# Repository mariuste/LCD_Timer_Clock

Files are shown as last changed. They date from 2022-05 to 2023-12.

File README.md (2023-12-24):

# Light Alarm Clock and Timer"
# Project Parameters
Name: "Light Alarm Clock and Timer"
Description: "Open Source, Alarm Clock with battery backup and USB-C Power"
Short Name: "Alarm_Clock"

# Description
/TODO/

# ToDos
- create requirements for redesign (single eval board, optimize encoder)
- define critical components (speakter interface)
- create schematic
- create layout

# Requirements for LED_board Mk2

## Changes to previous version

# Part selection
| Part | Manufacturer | Part Number |
|---|---|---|
| MCU | STM | STM32L011F3U6TR | /TBD/ other type

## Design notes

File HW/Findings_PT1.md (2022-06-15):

Findings

PCB_TOP
- variant problem in BOM (R502) -> [Issue #1](https://github.com/mariuste/LCD_Timer_Clock/issues/1)
- BTN LED resistor missing (here or on PCB-BOT); yellow 2k and green 16k -> [Issue #2](https://github.com/mariuste/LCD_Timer_Clock/issues/2)
- Identifier in solder mask wrong (top - bot) -> [Issue #3](https://github.com/mariuste/LCD_Timer_Clock/issues/3)
- Export File name missing "TOP" -> [Issue #4](https://github.com/mariuste/LCD_Timer_Clock/issues/4)
- IC503, IC504, IC505 EP is LED pin, not GND -> [Issue #5](https://github.com/mariuste/LCD_Timer_Clock/issues/5)
- add vias to LEDs to transport heat (full connection) -> [Issue #7](https://github.com/mariuste/LCD_Timer_Clock/issues/7)
- add heat sink from bottom -> [Issue #7](https://github.com/mariuste/LCD_Timer_Clock/issues/7)
- LCD_Keypad_PWM not connected -> bridge with BG PWM -> [Issue #8](https://github.com/mariuste/LCD_Timer_Clock/issues/8)
- add cover to BTN LEDs (too bright), maybe drill holes for mounting something -> [Issue #9](https://github.com/mariuste/LCD_Timer_Clock/issues/9)
- rename Set LED to Time_Date LED and other signals ("T" missing) -> [Issue #10](https://github.com/mariuste/LCD_Timer_Clock/issues/10)
- schematic net name timer / quicksetting not consistent with LEDs -> [Issue #10](https://github.com/mariuste/LCD_Timer_Clock/issues/10)
- Timer 1 LED is connected to signal Timer 2 and vice versa (for now fixed in sw) -> [Issue #10](https://github.com/mariuste/LCD_Timer_Clock/issues/10)
- LCD VDD too low, above 3V3 working -> use VBAT, mind voltage levels -> [Issue #11](https://github.com/mariuste/LCD_Timer_Clock/issues/11)
- LED not yellow enugh, replace with warmer color, e.g. XTEAWT-00-0000-00000LAEATR-ND or 475-GWQSSPA1.EM-LBLH-XX58-1-350-R18TR-ND -> [Issue #7](https://github.com/mariuste/LCD_Timer_Clock/issues/7)
- adjust max current for new LEDs -> [Issue #7](https://github.com/mariuste/LCD_Timer_Clock/issues/7)
- rename signal "nSW_QUICKSETTING_T" to "nSW_TIMER2_T" -> [Issue #10](https://github.com/mariuste/LCD_Timer_Clock/issues/10)
- rename signal "nSW_TIMER_T" to "nSW_TIMER1_T" -> [Issue #10](https://github.com/mariuste/LCD_Timer_Clock/issues/10)
- rename signal "nSW_SET_" to "nSW_TIME_DATE_T" -> [Issue #10](https://github.com/mariuste/LCD_Timer_Clock/issues/10)

PCB_BOT
- silk of LEDs swapped (standby and charge) -> [Issue #12](https://github.com/mariuste/LCD_Timer_Clock/issues/12)
- IC302 silk pin1 not visible -> [Issue #12](https://github.com/mariuste/LCD_Timer_Clock/issues/12)
- IC400 assembly pin1 missing -> [Issue #12](https://github.com/mariuste/LCD_Timer_Clock/issues/12)
- SW302 wrong type (resistor) -> [Issue #12](https://github.com/mariuste/LCD_Timer_Clock/issues/12)
- assembly plan not cleaned up -> [Issue #12](https://github.com/mariuste/LCD_Timer_Clock/issues/12)
- stencil cutouts for bat connectors (keepout holes) -> [Issue #13](https://github.com/mariuste/LCD_Timer_Clock/issues/13)
- Identifier in solder mask wrong (top - bot) -> [Issue #12](https://github.com/mariuste/LCD_Timer_Clock/issues/12)
- J200 +/- missing -> [Issue #12](https://github.com/mariuste/LCD_Timer_Clock/issues/12)
- J200 add some clearance to J400 -> [Issue #14](https://github.com/mariuste/LCD_Timer_Clock/issues/14)
- 3V0 Ref not properly working at low bat voltages -> use VBUS anyway -> [Issue #15](https://github.com/mariuste/LCD_Timer_Clock/issues/15)
- DFP Audio en pull-down -> [Issue #16](https://github.com/mariuste/LCD_Timer_Clock/issues/16)
- Keepout for programmer backplate -> [Issue #13](https://github.com/mariuste/LCD_Timer_Clock/issues/13)
- Move SWD to clear gear -> [Issue #14](https://github.com/mariuste/LCD_Timer_Clock/issues/14)
- Add pinheader for swd for standard connection -> [Issue #17](https://github.com/mariuste/LCD_Timer_Clock/issues/17)
- add 0R to en of IC203 to analyze current -> [Issue #17](https://github.com/mariuste/LCD_Timer_Clock/issues/17)
- Export File name missing BOT -> [Issue #12](https://github.com/mariuste/LCD_Timer_Clock/issues/12)
- Silk of Battery much larger symbol -> [Issue #12](https://github.com/mariuste/LCD_Timer_Clock/issues/12)
- LCD_Keypad_PWM not connected -> [Issue #18](https://github.com/mariuste/LCD_Timer_Clock/issues/18)
- DS300 pin 1 marking missing -> [Issue #12](https://github.com/mariuste/LCD_Timer_Clock/issues/12)
- Battery connectors too far apart, check distance -> [Issue #13](https://github.com/mariuste/LCD_Timer_Clock/issues/13)
- flip programmer to bottom side -> [Issue #14](https://github.com/mariuste/LCD_Timer_Clock/issues/14)
- DFPlayer is flipped in two axis -> [Issue #13](https://github.com/mariuste/LCD_Timer_Clock/issues/13)
- speaker is way too weak (lloks like ear piece), replace with stronger speaker -> [Issue #17](https://github.com/mariuste/LCD_Timer_Clock/issues/17)
- add / edit I2C adress of RTC in schematic (0xA4) -> [Issue #12](https://github.com/mariuste/LCD_Timer_Clock/issues/12)
- rename Set LED to Time_Date LED  -> [Issue #19](https://github.com/mariuste/LCD_Timer_Clock/issues/19)
- comment of EEPROM im schematic is not helpfull -> change to AT34C04 -> [Issue #12](https://github.com/mariuste/LCD_Timer_Clock/issues/12)
- add high side switch between VBUS and D401 to be able to power LED from VBAT even if a 0.9A USB power supply is attached. E.g. control High side with  "nUSB_PD_OK" this way monitoring this signal is not necessary any more. -> [Issue #17](https://github.com/mariuste/LCD_Timer_Clock/issues/17)
- rename signal "nSW_QUICKSETTING" to "nSW_TIMER2" -> [Issue #19](https://github.com/mariuste/LCD_Timer_Clock/issues/19)
- rename signal "nSW_TIMER" to "nSW_TIMER1" -> [Issue #19](https://github.com/mariuste/LCD_Timer_Clock/issues/19)
- rename signal "nSW_SET" to "nSW_TIME_DATE" -> [Issue #19](https://github.com/mariuste/LCD_Timer_Clock/issues/19)
- EEPROM text schematic: "Address: 0xA0" -> [Issue #12](https://github.com/mariuste/LCD_Timer_Clock/issues/12)

- Idle current consumption
  - 5mA at 64 MHz
  - 4.0mA at 4MHz (higher than expected)
  - 1.3mA at 1MHz (higher than expected)

MECHANICS
- Fix bearings
- add speaker Mount

COMMENTS
- use BAT down to 3.4V (lcd gets less and less visible)
- when nUSB_PD_OK = high, consider power budget to be 900 mA; charging max is 400 mA, therefore LEDs should be in sum <= 900mA - 400 mA (charging) - 300mA (DFPlayer) - 20mA (remaining circuit) = 180 mA (add some tolerance). Consider sum of main LEDs as well as background lighting LEDs -> see PCB_Bot "add high side switch between VBUS and D401" to eliminate this requirement ([Issue #17](https://github.com/mariuste/LCD_Timer_Clock/issues/17)). LEDs can be driven at full power at any time this this change. I assume the ouput of IC201 is limited to 400 mA at any time.
- don't use low temp solder for PCB_TOP(LEDs >= 100°C)

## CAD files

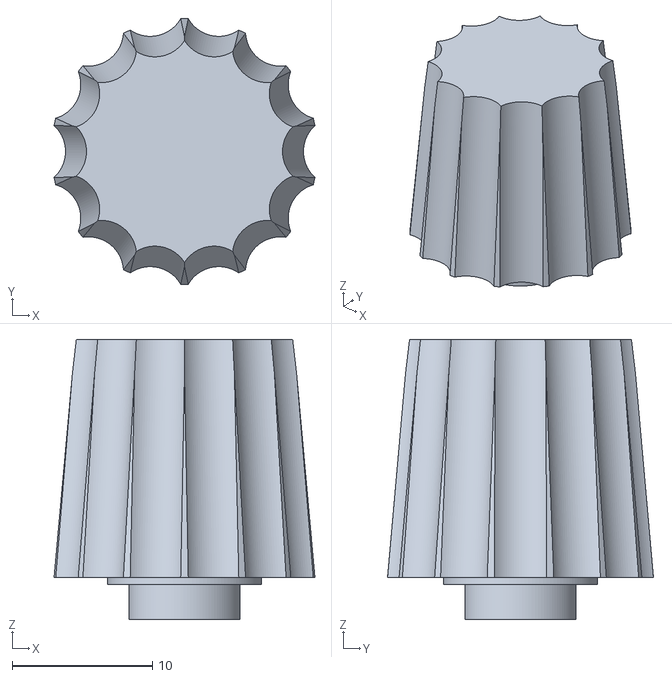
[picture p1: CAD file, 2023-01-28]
HW/Construction/Knob.stl
18.6 x 19.0 x 20.0

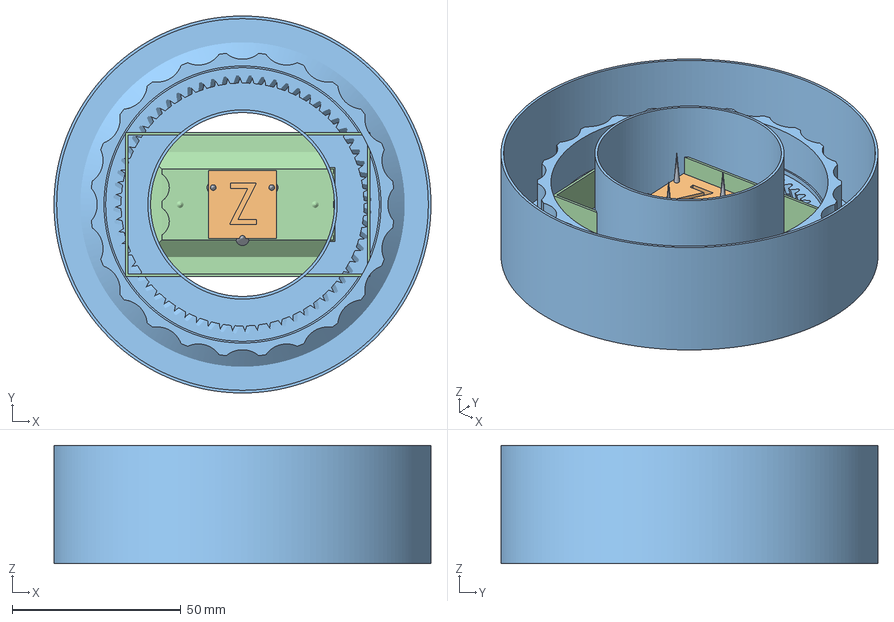
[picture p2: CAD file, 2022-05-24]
HW/Construction/Molds/Molds_Slicer.3mf
111.6 x 111.6 x 35.0 mm
stringing_test.stl
xyzCalibration_cube.stl
Ring_Top_Silicone_Mold.stl
BG_Diffusor_Silicone_Mold.stl

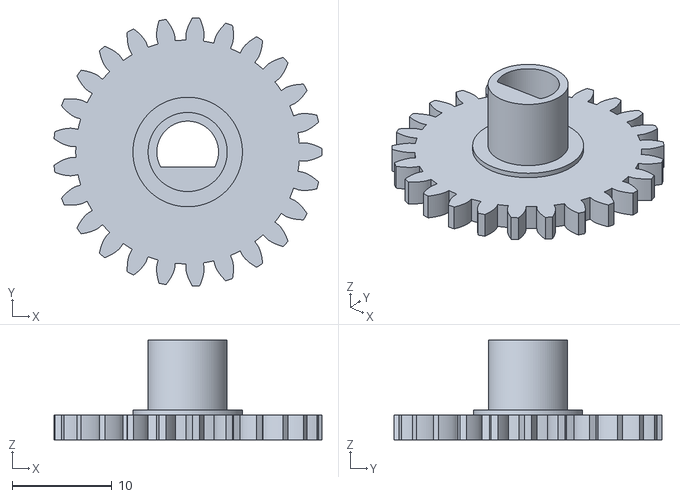
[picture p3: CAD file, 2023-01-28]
HW/Construction/Encoder_Gear.stl
26.9 x 27.0 x 10.0

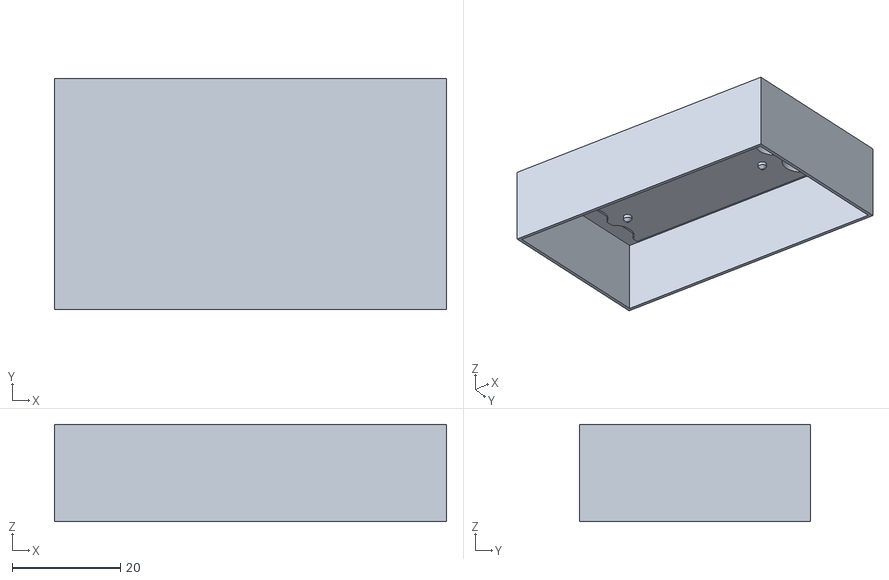
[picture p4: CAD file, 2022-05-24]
HW/Construction/Molds/BG_Diffusor_Silicone_Mold.stl
72.4 x 42.6 x 18.0

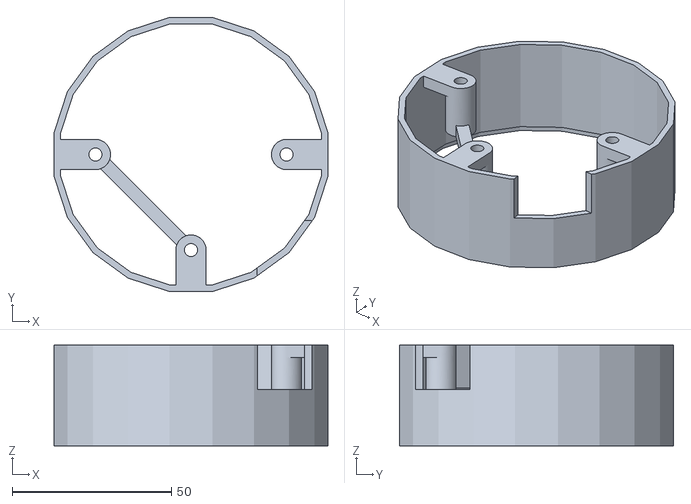
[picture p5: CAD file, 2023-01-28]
HW/Construction/Enclosure_Top.stl
86.0 x 86.0 x 31.7

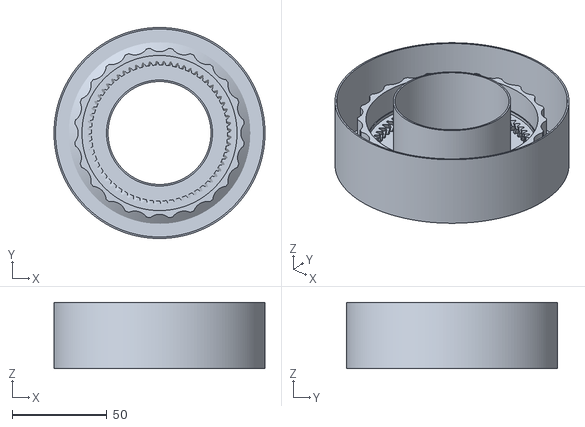
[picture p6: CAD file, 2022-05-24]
HW/Construction/Molds/Ring_Top_Silicone_Mold.stl
111.6 x 111.6 x 35.0

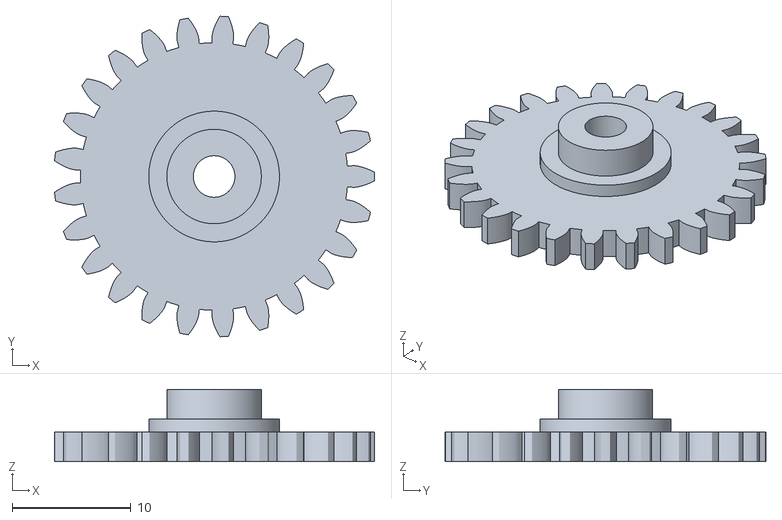
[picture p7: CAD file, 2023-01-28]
HW/Construction/Knob_Gear.stl
26.9 x 27.0 x 6.10

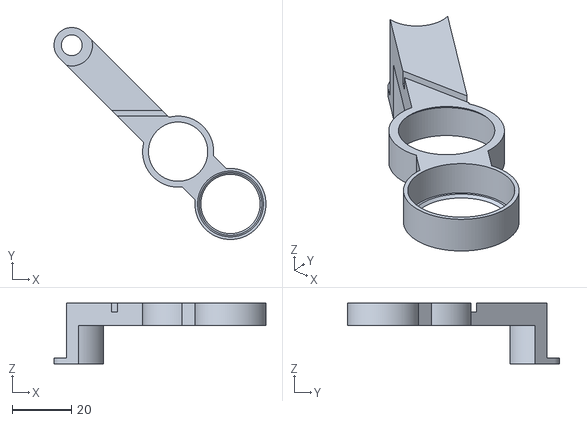
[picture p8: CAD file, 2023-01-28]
HW/Construction/Knob_Mount.stl
71.6 x 71.6 x 20.6

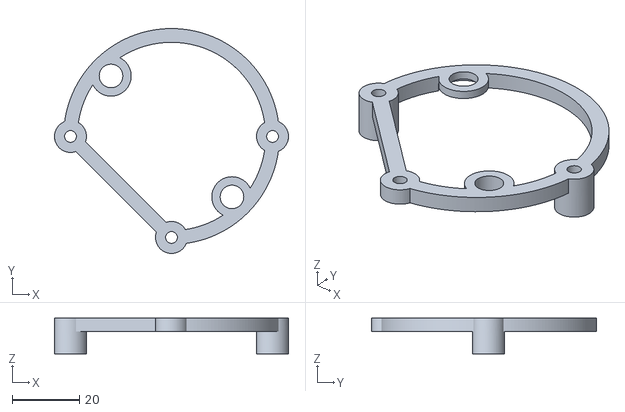
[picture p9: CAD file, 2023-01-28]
HW/Construction/PCB_Mount_Bot.stl
69.5 x 66.8 x 10.6

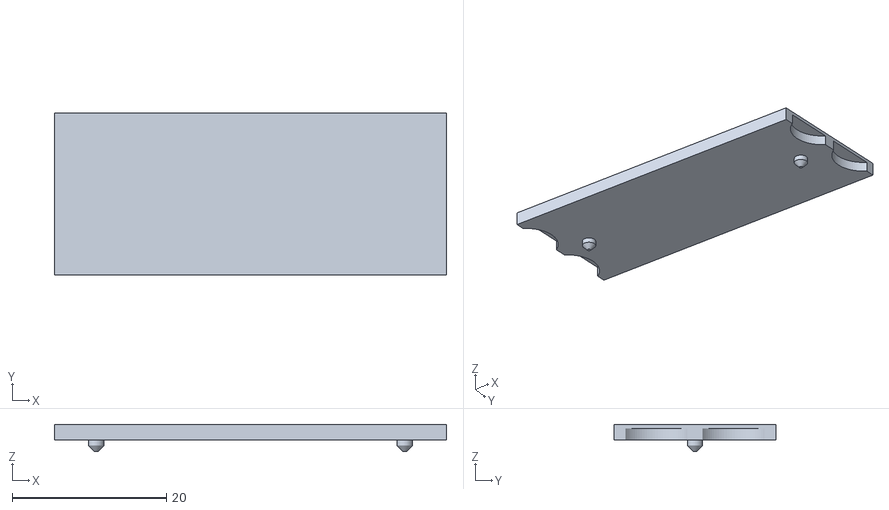
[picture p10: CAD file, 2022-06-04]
HW/Construction/VI-402-DP-FC-S_Backlight v13.stl
50.8 x 21.0 x 3.50

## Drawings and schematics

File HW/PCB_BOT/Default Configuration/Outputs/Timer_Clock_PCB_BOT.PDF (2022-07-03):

Quantity | Designator | Type | Comment | Description | Manufacturer | Manufacturer Part Number | LibRef | Supplier 1 | Supplier Part Number 1
2 | C300, C304 | Capacitor | C 10nF 0402 16V | CAP CER 10000PF 16V Y5V 0402 | Samsung Electro-Mechanics | CL05F103ZO5NN NC | CAP_10nF_16V_0 402 | Digi-Key | 1276-1738-1-ND
2 | C307, C308 | Capacitor | C 5.6pF 0402 50V | CAP CER 5.6PF 50V C0G/NP0 0402 | Samsung Electro-Mechanics | CL05C5R6DB5NN NC | CAP_5.6PF_50V_0 402 | Digi-Key | 1276-1712-1-ND
| C200, C301, C302, C303 | Capacitor | C 1nF 0402 50V | CAP CER 1000PF 50V C0G/NP0 0402 | Murata Electronics | GRM1555C1H102 JA01J | CAP_1nF_50V_04 02 | Digi-Key | 490-6190-1-ND
4 | C201, C202, C203, C208 | Capacitor | C 10uF 0603 6.3V | CAP CER 10UF 6.3V X5R 0603 | Taiyo Yuden | JMK107ABJ106M A-T | CAP_10uF_6V3_0 603 | Digi-Key | 587-5869-1-ND
8 | C204, C205, C206, C207, C209, C305, C306, C400 | Capacitor | C 100nF 0402 10V | CAP CER 0.1UF 10V X5R 0402 | Samsung Electro-Mechanics | CL05A104MP5NN NC | CAP_100nF_10V_ 0402 | Digi-Key | 1276-1443-1-ND
1 | J202 | Connector | TYPE-C-31-M-17 | USB4 GEN3, TYPE C, TOP MOUNT | Korean Hroparts Elec | TYPE-C-31-M-17 | J_USB-C_2 | LCSC | C283540
1 | J300 | Connector | PH2 | CONN HEADER R/A 2POS 2MM | JST Sales America Inc. | S2B-PH-KL(LF)(SN) | J_S2B-PH-KL | LCSC | C160237
1 | J301 | Connector | CON | CONN CONNECTOR PH 2POS 2MM | JST Sales America Inc. | PHR-2-R | J_PHR-2-R | LCSC | C398543
1 | J305 | Connector | 5x2 | CONN HEADER SMD 10POS 1.27MM | Sullins Connector Solutions | GRPB052VWQS-RC | J_MH5x2_1.27 | Digi-Key | S9012E-05-ND
1 | J400 | Connector | FPC24 | CONN FPC BOT 24 PIN 1mm Pitch | MOLEX | 522712479 | J_FPC24_DS | LCSC | C293627
2 | J302, J303 | Connector | PIN | PIN INSERT | JST Sales America Inc. | SPH-004T-P0.5S | J_PHR-2-R_PIN | LCSC | C160351
2 | D300, D301 | Diode | BAS20LT3G | DIODE GP 200V 200MA SOT23-3 | onsemi | BAS20LT3G | D_LL_200V_200m A | Digi-Key | BAS20LT3GOSCT-ND
2 | D400, D401 | Diode | D SCH 40V 5A | DIODE SCHOTTKY 40V 5A DO214AB | Comchip Technology | CDBC540-G | D_SCH_40V_5A | Digi-Key | 641-1126-1-ND
1 | D201 | Diode, LED | LED G | LED GREEN DIFFUSED 0603 SMD | OSRAM Opto Semiconductors Inc. | LT Q39G-Q1OO-25-1 | D_LED_Green_06 03 | Digi-Key | 475-3442-1-ND
2 | D202, D302 | Diode, LED | LED Y | LED YELLOW DIFFUSED | Stanley Electric Co | FKY1111C-TR | D_LED_Yellow_06 03 | Digi-Key | 404-1273-1-ND
1 | D200 | Diode, TVS | TVS_4 5V | TVS DIODE 5VWM 12.5VC SOT23-6 | Comchip Technology | CPDT6-5V0UPC-HF | D_TVS_U4_12V5 | Digi-Key | 641-1829-1-ND
1 | IC200 | IC | DW01A | IC BATT MANAGEMENT SOT-23-6 | PUOLOP | DW01A | IC_BAT_PROT_D W01A | LCSC | C351410
1 | IC201 | IC | TP4056-42 | IC BATT CHG LI-ION 1CELL ESOP-8-EP | TOPPOWER(Nanj ing Extension Microelectronics) | TP4056-42-ESOP8 | IC_BAT_CHGR_TP 4056 | LCSC | C16581
1 | IC400 | IC, Driver | SX1503I091TRT | IC GPIO EXPANDER I2C 16CH 28-QFN | Semtech Corporation | SX1503I091TRT | IC_16ch_Port_Ext ender_2 | Digi-Key | SX1503I091CT-ND
1 | IC301 | IC, EEPROM | AT34C04-X5M | IC EEPROM 4KBIT I2C 1MHZ 8TSSOP | Microchip Technology | AT34C04-X5M-T | IC_EEPROM_AT3 4C04 | Digi-Key | AT34C04-X5M-TCT-ND
1 | IC302 | IC, MCU | STM32G031F8P6 | IC MCU 32BIT 32KB FLASH 20TSSOP | STMicroelectroni cs | STM32G031F8P6 | IC_MCU_STM32G 031F8P6 | LCSC | C529334
1 | IC202 | IC, OpAmp | MCP6007-E/SN | DUAL, 1MHZ OP AMP, E TEMP | Microchip Technology | MCP6007-E/SN | IC_OpAmp_MCP 6007-E/SN | Digi-Key | 150-MCP6007-E/SN-ND
1 | IC204 | IC, Reference | VREF 3V0 | IC VREF SHUNT 1% SOT23-3 | Texas Instruments | LM4040DIM3X-3.0/NOPB | IC_Ref_LM4040DI M3X-3.0 | Digi-Key | 296-41429-1-ND
1 | IC203 | IC, Regulator | TCR2LF30 | IC REG LINEAR 3V 200MA SMV | Toshiba Semiconductor and Storage | TCR2LF30,LM(CT | IC_Reg_TCR2LF3 0 | Digi-Key | TCR2LF30LM(CTCT-ND
1 | IC300 | IC, RTC | RV-3028-C7 | IC RTC CLK/CALENDAR I2C 10SON | Micro Crystal AG | RV-3028-C7TAQC | IC_RTC_3028-C7 | Mouser | 428-203591-MG01
1 | L200 | Inductor, Ferrite | L Ferrite 100R 4A | FIXED IND 100 4000MA 1206 | Eaton -Electronics Division | MFBM1V3216-101-R | L_100R_4A | Digi-Key | 283-MFBM1V3216-101-RCT-ND
1 | DS300 | other | DFP Mini-YX5200 | Mini-YX5200 Audio MP3 Modul | DFRobot | DFR0299 | DFP_Player_mini | AliExpress | 33036928283
1 | J203 | other | BAT | SMT Battery Connectors 18650 | MYOUNG | MY-18650-02 | J_BAT_CLIP_1865 0_A | LCSC | C2979182
1 | J204 | other | BAT | SMT Battery Connectors 18650 | MYOUNG | MY-18650-02 | J_BAT_CLIP_1865 0_B | LCSC | C2979182
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

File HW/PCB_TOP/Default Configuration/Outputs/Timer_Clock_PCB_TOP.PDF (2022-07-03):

Quantity | Designator | Type | Comment | Description | Manufacturer | Manufacturer Part Number | LibRef | Supplier 1 | Supplier Part Number 1
8 | C500, C501, C502, C503, C504, C505, C506, C507 | Capacitor | C 2.2uF 0402 6.3V | CAP CER 2.2UF 6.3V X6T 0402 | Murata Electronics | GRM155D80J225 ME95D | CAP_2.2uF_6V3_ 0402 | Digi-Key | 490-10450-1-ND
1 | J500 | Connector | FPC24 | CONN FPC BOT 24 PIN 1mm Pitch | MOLEX | 522712479 | J_FPC24_DS | LCSC | C293627
1 | D506 | Diode, LED | LED Y | LED YELLOW DIFFUSED | Stanley Electric Co | FKY1111C-TR | D_LED_Yellow_06 03 | Digi-Key | 404-1273-1-ND
3 | D513, D514, D515 | Diode, LED | LED W | LED XLAMP WARM WHT 2700K SMD | CreeLED, Inc. | XTEAWT-E0-0000-00000HEE8 | D_LED_W_HP_3 | Digi-Key | XTEAWT-E0-0000-00000HEE8TR-ND
4 | D504, D505, D507, D508 | Diode, LED | LED G | LED GREEN DIFFUSED 0603 SMD | OSRAM Opto Semiconductors Inc. | LT Q39G-Q1OO-25-1 | D_LED_Green_06 03 | Digi-Key | 475-3442-1-ND
8 | D500, D501, D502, D503, D509, D510, D511, D512 | Diode, LED | LED W | LED WHITE SIDE SMD | Everlight Elec | 99-218UMC/1637CD /TR8-T | D_LED_White_s | LCSC | C710226
1 | IC501 | IC, Driver | BL55072A-R | IC LCD DRIVER 36SEG TSSOP-48 | BL(Shanghai Belling) | BL55072A-R | IC_LCD_cntr_BL5 5072A-R | LCSC | C524044
2 | IC500, IC502 | IC, Driver | MIC2841AYMT | IC LED DRIVER 4 CH | Microchip Technology | MIC2841AYMT-TR | IC_LED_cntr_MIC 2841 | Mouser | 998-MIC2841AYMTTR
3 | IC503, IC504, IC505 | IC, Driver | OC7140 | IC LED DRIVER 1 CH 2A ESOP8 | OCX | OC7140 | IC_LED_cntr_OC7 140 | LCSC | C842736
1 | CABLE500 | other | FPC24p80mm | FPC Cable 1mm Pitch 24Pin 80mm Opposite Sides | LX | C50299 | CABLE_FPC24_80 | LCSC | C50299
3 | HS500, HS501, HS502 | other | Heatsink | Heatsink 6.5mm x 6.5mm | Alphacool | 17425 | Heatsink_6.5x6.5 | Amazon | B077VQTB6Q
5 | SW500, SW501, SW502, SW503, SW504 | other | SW | SWITCH TACTILE SW-SMD | BRIGHT | TSA063G50-250 | SW_TactileSW_V _2 | LCSC | C294565
1 | DS500 | other, Display | LCD 4x1 | LCD MOD 4 DIG 4 X 1 REFLECTIVE | Varitronix | VI-402-DP-RC-S | DISPL_7SEG_4x1 | Digi-Key | 153-1135-ND
1 | R513 | Resistor | R 2k 0402 | RES 2K OHM 1% 1/16W 0402 | Stackpole Electronics Inc | RMCF0402FT2K0 0 | R_2k_0402 | Digi-Key | RMCF0402FT2K00 CT-ND
3 | R506, R509, R510 | Resistor | R 0R27 1206 | RES 0.27 OHM 1% 1/3W 1206 | RALEC | RTT06R270FTP | R_0R27_1206 | LCSC | C104939
3 | R518, R519, R520 | Resistor | R 270k 0402 | RES 270K OHM 1% 1/16W 0402 | YAGEO | RC0402FR-07270KL | R_270k_0402 | Digi-Key | 311-270KLRCT-ND
4 | R500, R501, R503, R504 | Resistor | R 10k 0402 | RES 10K OHM 1% 1/16W 0402 | YAGEO | RC0402FR-0710KL | R_10k_0402 | Digi-Key | 311-10.0KLRCT-ND
4 | R511, R512, R514, R515 | Resistor | R 16k 0402 | RES 16K OHM 1% 1/16W 0402 | Stackpole Electronics Inc | RMCF0402FT16K 0 | R_16k_0402 | Digi-Key | RMCF0402FT16K0 CT-ND
5 | R505, R507, R508, R516, Re si stor | R 0R0 0402 | RES 0 OHM JUMPER 1/16W 0402 | Stackpole ElectronRM CF0402ZT0R00 R_0R0_0402 | Digi-Key | RMCF0402ZT0R00CT-ND

## Electrical Rules Check Report

Class | Document | Message Successful Compile for Timer_Clock_TOP.PrjPcb
Sonntag 3 Jul 2022 3:20:58 PM | Page 1 of 1

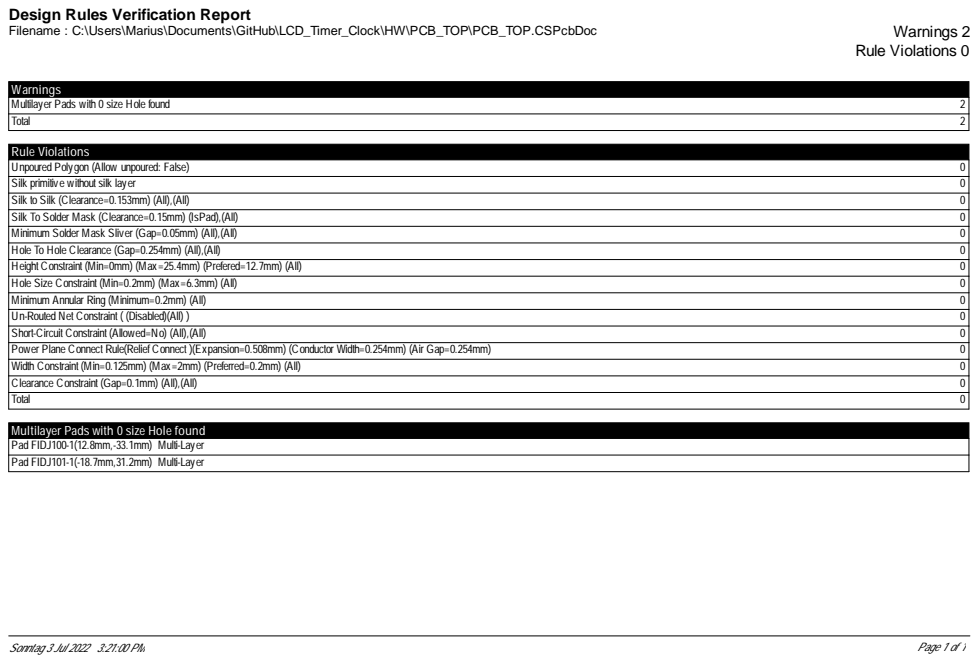
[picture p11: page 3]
Filename : C:\Users\Marius\Documents\GitHub\LCD_Timer_Clock\HW\PCB_TOP\PCB_TOP.CSPcbDoc; Warnings 2; Rule Violations 0; Multilayer Pads with 0 size Hole found; Rule Violations; Unpoured Polygon (Allow unpoured: False); Silk primitive without silk layer; Silk to Silk (Clearance=0.153mm) (All),(All); Silk To Solder Mask (Clearance=0.15mm) (IsPad),(All); Minimum Solder Mask Sliver (Gap=0.05mm) (All),(All); Hole To Hole Clearance (Gap=0.254mm) (All),(All)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

Design Rules Verification Report

Multilayer Pads with 0 size Hole found
Pad FIDJ100-1(12.8mm,-33.1mm) Multi-Layer
Pad FIDJ101-1(-18.7mm,31.2mm) Multi-Layer

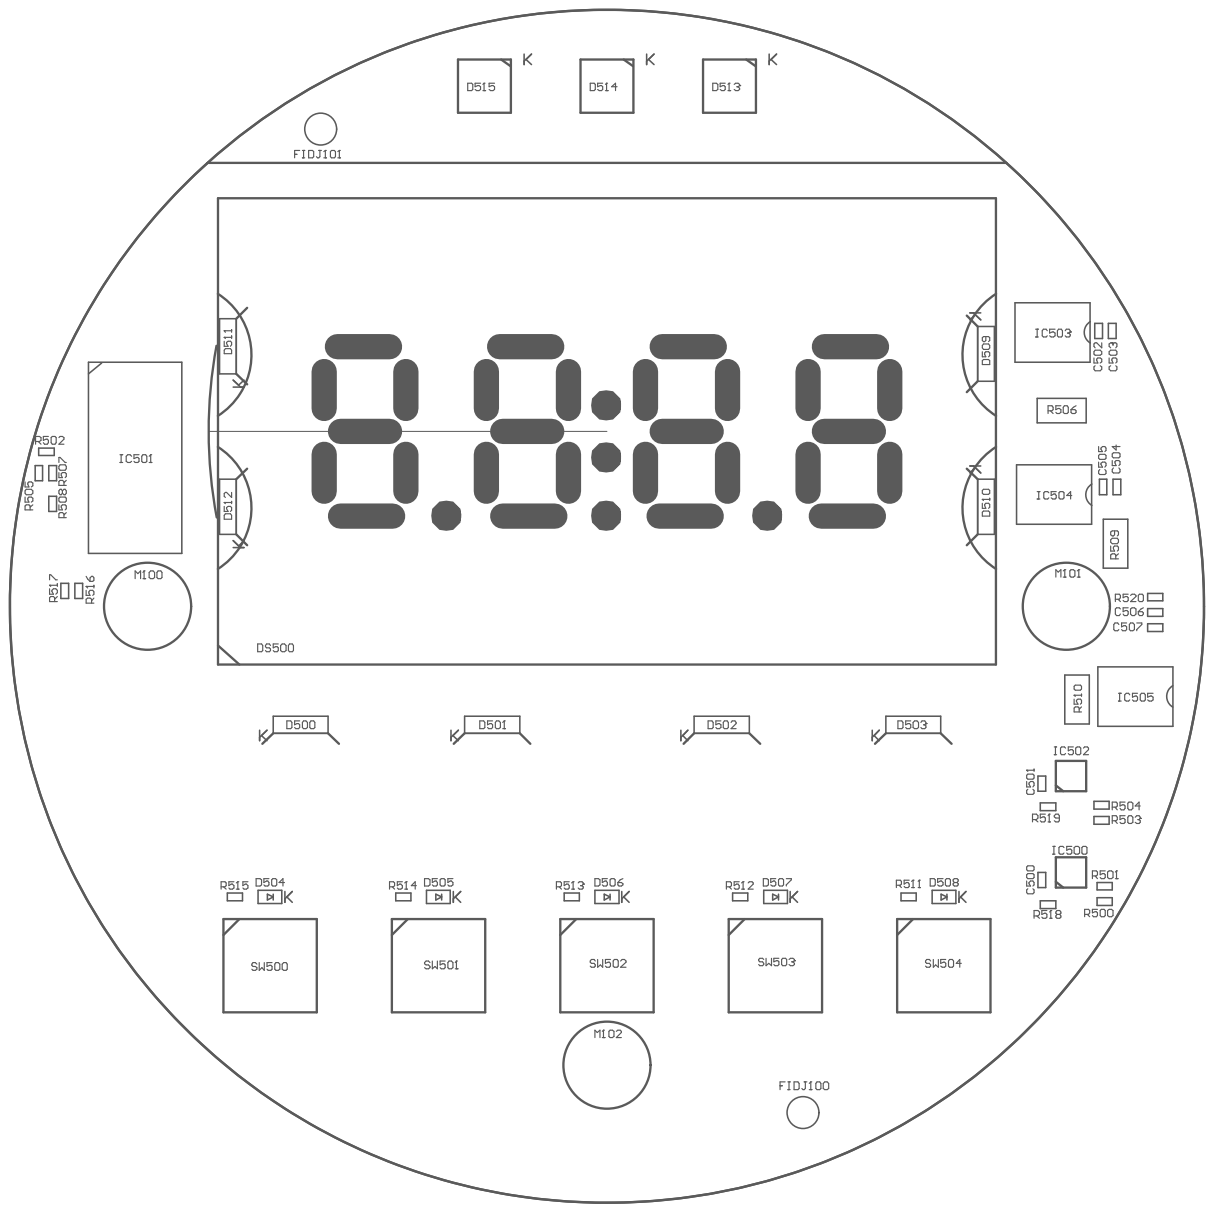
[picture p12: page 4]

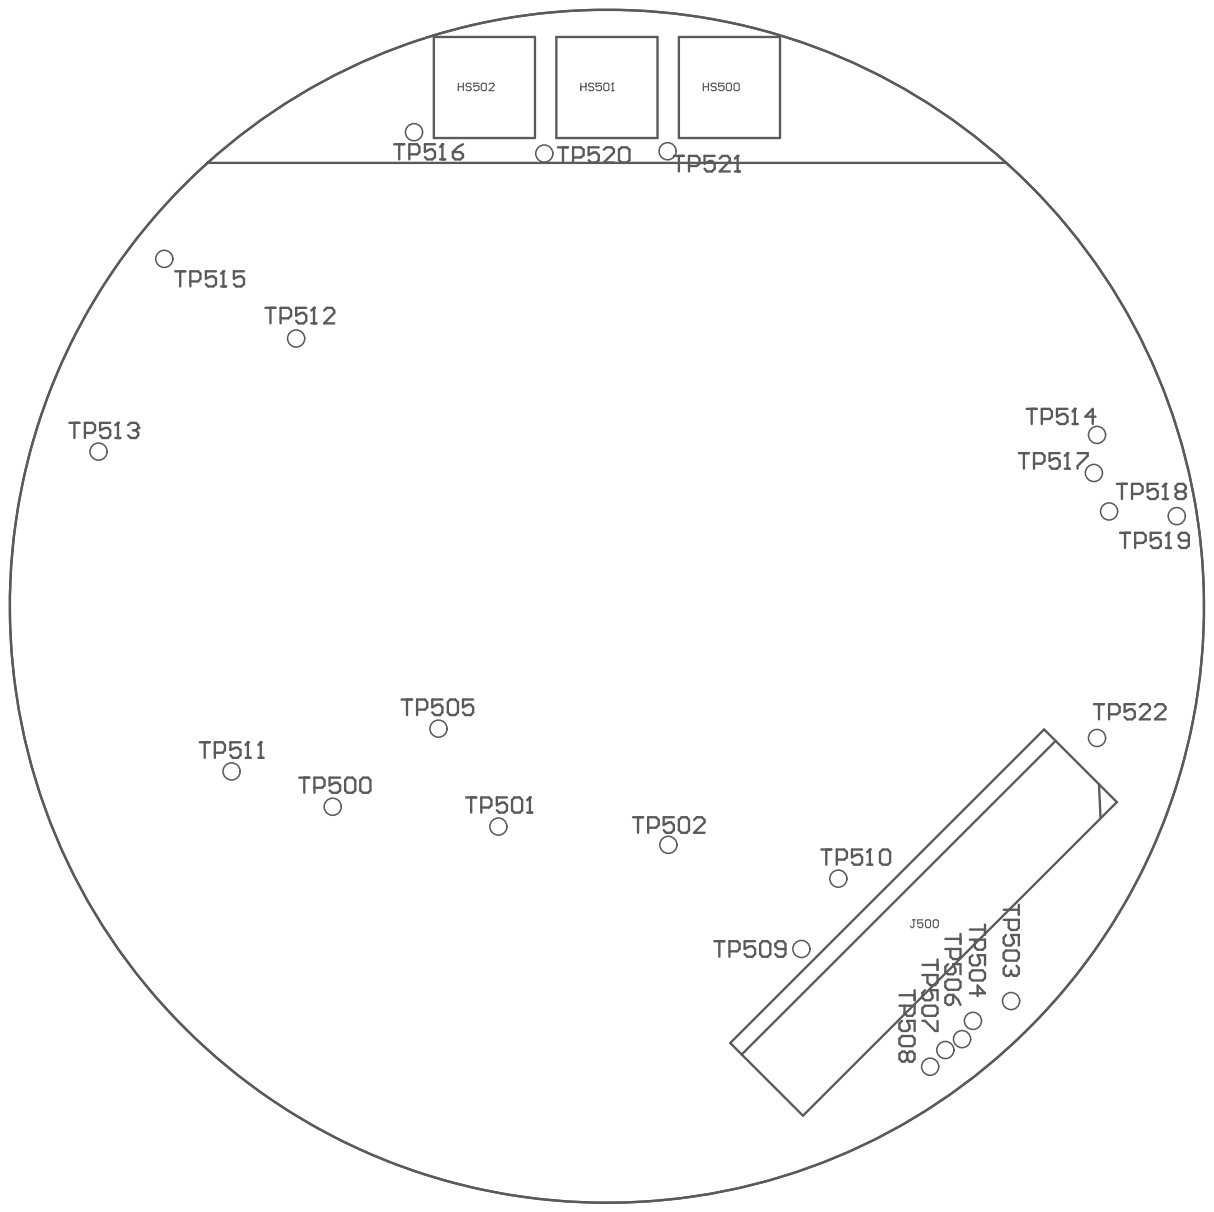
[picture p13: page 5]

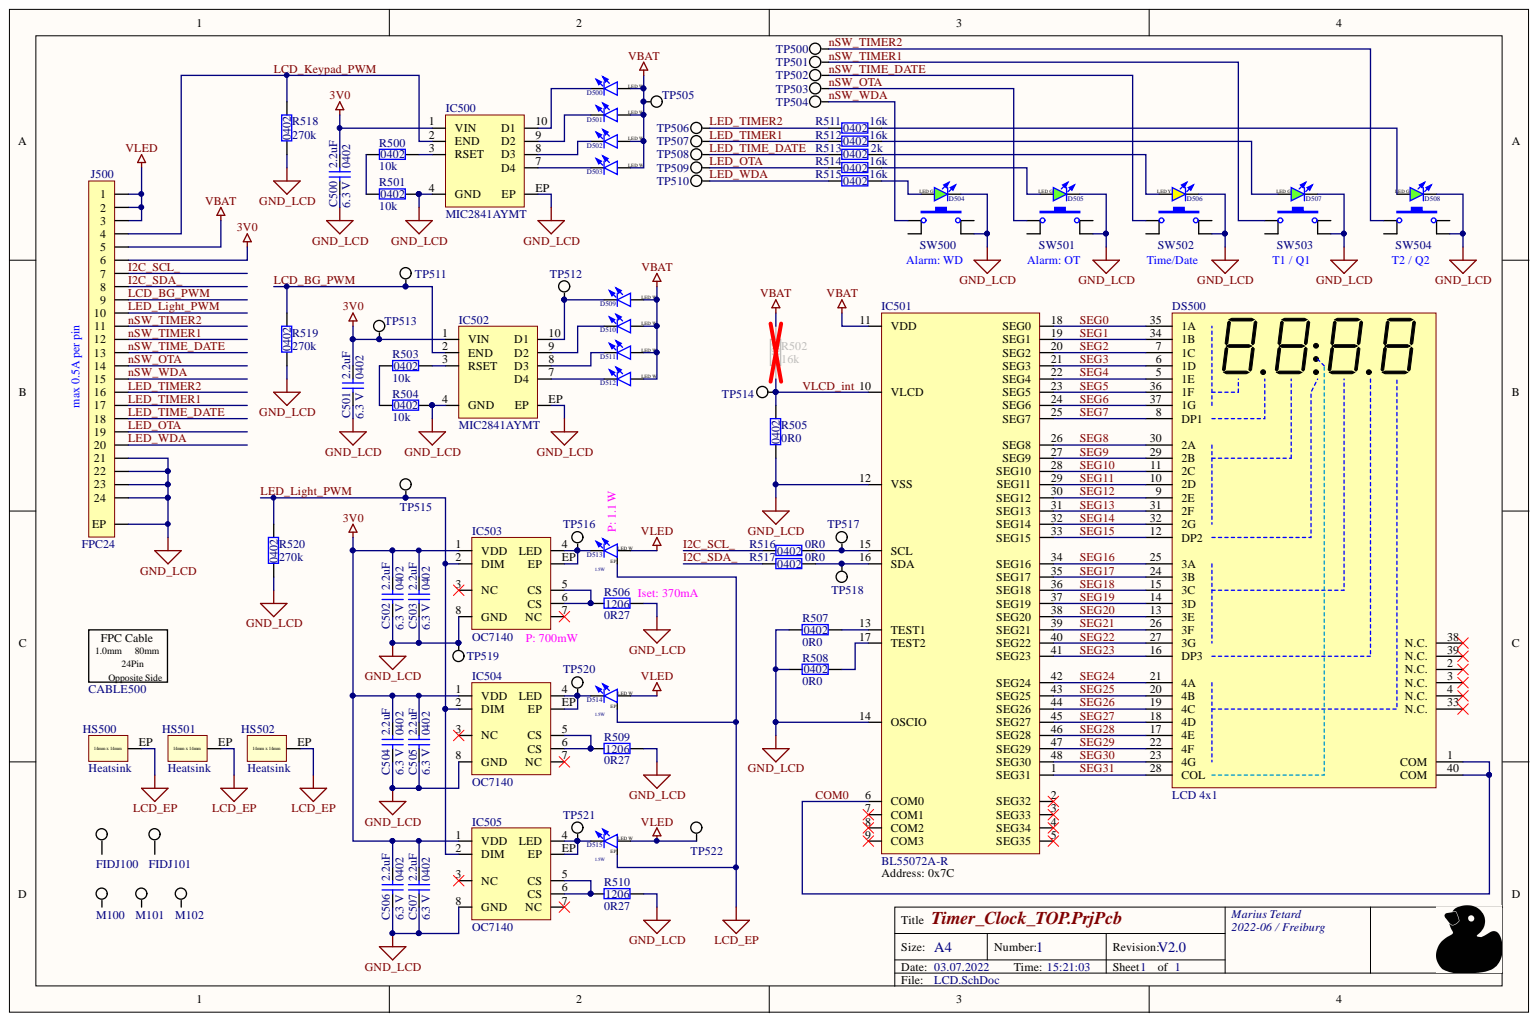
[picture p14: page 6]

COM0 | SEG29 | 4F 22

Timer_Clock_TOP.PrjPcb Title | Marius Tetard 2022-06 / Freiburg

A4 Size: | 1 Number: | V2.0 Revision:
Date: 03.07.2022 Time: 15:21:03 | | Sheet 1 of 1

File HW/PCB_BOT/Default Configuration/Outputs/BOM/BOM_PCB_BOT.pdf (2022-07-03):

03.07.22, 15:22 | MainGrid

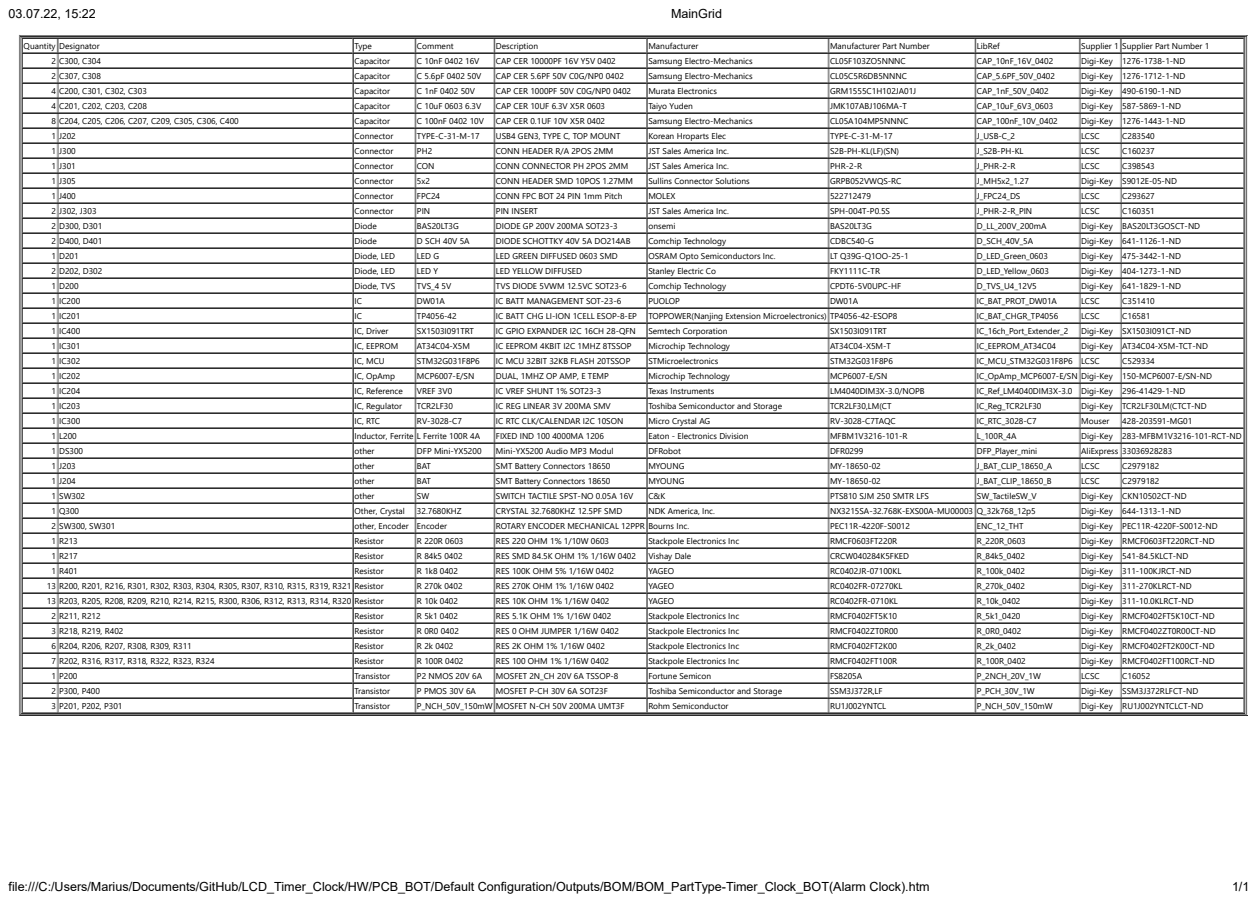
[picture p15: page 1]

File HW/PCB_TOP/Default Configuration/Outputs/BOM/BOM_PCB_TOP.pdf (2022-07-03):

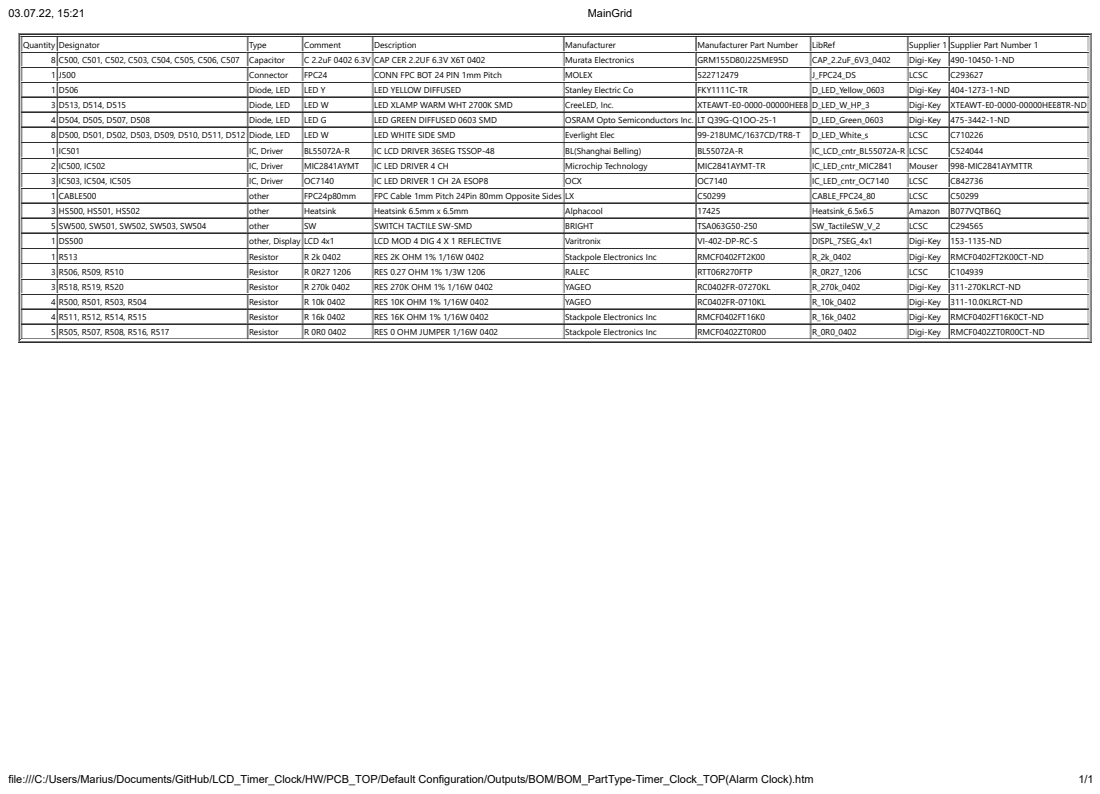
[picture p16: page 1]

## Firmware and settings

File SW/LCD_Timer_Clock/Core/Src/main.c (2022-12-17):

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
/* Includes ------------------------------------------------------------------*/
#include "main.h"

/* USER CODE BEGIN Includes */
#include "BL55072A.h"	// LCD control
#include "HMI.h"		// HMI (LEDs and Buttons)
#include "RV3028.h" 	// RTC
#include "AT34C04.h"	// EEPROM

/* USER CODE END Includes */

ADC_HandleTypeDef hadc1;

I2C_HandleTypeDef hi2c2;

RTC_HandleTypeDef hrtc;

TIM_HandleTypeDef htim1;
TIM_HandleTypeDef htim2;
TIM_HandleTypeDef htim3;

UART_HandleTypeDef huart2;

/* USER CODE BEGIN PV */

// Sate Machine ###############################################################
int currentState = STATE_INITIALISATION;
int nextState = STATE_INITIALISATION;

// Set timeout time
uint8_t TIMEOUT_SHORT = 1;
uint8_t TIMEOUT_MEDIUM = 2;
uint8_t TIMEOUT_LONG = 4;
uint8_t TIMEOUT_EXTRA_LONG = 30;
uint8_t TIMEOUT_ALARM = 180;

uint8_t TIMEOUT_DOUBLE_PRESS = 2;

// counts loops for blinking segments
uint8_t loop_counter;
// blink intervals
uint8_t blink_slow_interval = 5;
uint8_t blink_fast_interval = 2;

// Toggling blink signals
uint8_t blink_signal_fast = 1;
uint8_t blink_signal_slow = 1;
// TODO create seconds blink pattern with rtc

uint8_t override_blink = 0;

// UNIX time stamp
uint32_t LastEvent = 0;

// Define external ICs ########################################################
// Human Machine Interface (buttons, led) -------------------
HMI myHMI;

// counter to detect long press of buttons
uint8_t HMI_BTN_ENCODER_LONG_COUNTER = 0;
uint8_t HMI_BTN_WDA_LONG_COUNTER = 0;
uint8_t HMI_BTN_OTA_LONG_COUNTER = 0;
uint8_t HMI_BTN_TIME_DATE_LONG_COUNTER = 0;
uint8_t HMI_BTN_TIMER1_LONG_COUNTER = 0;
uint8_t HMI_BTN_TIMER2_LONG_COUNTER = 0;

// counter to detect amount of edges of buttons
uint8_t HMI_BTN_WDA_FALLING_EDGE_COUNTER = 0;
uint8_t HMI_BTN_WDA_LAST_STATE = BUTTON_NOT_PRESSED;
uint8_t HMI_BTN_OTA_FALLING_EDGE_COUNTER = 0;
uint8_t HMI_BTN_OTA_LAST_STATE = BUTTON_NOT_PRESSED;
uint8_t HMI_BTN_TIMER1_FALLING_EDGE_COUNTER = 0;
uint8_t HMI_BTN_TIMER1_LAST_STATE = BUTTON_NOT_PRESSED;
uint8_t HMI_BTN_TIMER2_FALLING_EDGE_COUNTER = 0;
uint8_t HMI_BTN_TIMER2_LAST_STATE = BUTTON_NOT_PRESSED;

// LOCK buttons after press
uint8_t HMI_BTN_ENCODER_LOCK = 0;
uint8_t HMI_BTN_WDA_LOCK = 0;
uint8_t HMI_BTN_OTA_LOCK = 0;
uint8_t HMI_BTN_TIME_DATE_LOCK = 0;
uint8_t HMI_BTN_TIMER1_LOCK = 0;
uint8_t HMI_BTN_TIMER2_LOCK = 0;

// brightness of Lamp
float LAMP_brightness_setting = PWM_CH_LAMP_MIN;
float LAMP_brightness_current_level = 0;
float LAMP_brightness_ALARM = 5;
// state of Lamp
uint8_t LAMP_state = 0;

// default brightness
uint8_t brightness_backlight_default = 150;
uint8_t brightness_keypad_default = 100;
uint8_t brightness_LCD_backlight = 100;
uint8_t brightness_keypad = 0;

// Encoder position as temporary storage across states
float encoder_pos = 0;

// LCD interface --------------------------------------------
LCD myLCD;

// RTC RV-3028 --------------------------------------------
RV3028 myRTC;

// for setting alarms and times
float TEMP_TIME_HOUR = 5;
float TEMP_TIME_MINUTE = 0;
float TEMP_TIME_SECONDS = 0;

float TEMP_TIMER1_INDEX = 1;
float TEMP_TIMER2_INDEX = 1;

float TEMP_QS1_INDEX = 1;
float TEMP_QS2_INDEX = 1;

float TEMP_DATE_YEAR = 22;
float TEMP_DATE_MONTH = 01;
float TEMP_DATE_DAY = 01;

// EEPROM -------------------------------------------------
AT34C04 myAT34C04;

// Analog intput -------------------------------------------------
// TODO maybe out source to HMI.h
// conversion Constant
const float VBAT_const = (3.0 / 4096) * 2;


/* USER CODE END PV */

void SystemClock_Config(void);
static void MX_GPIO_Init(void);
static void MX_ADC1_Init(void);
static void MX_I2C2_Init(void);
static void MX_TIM1_Init(void);
static void MX_TIM3_Init(void);
static void MX_USART2_UART_Init(void);
static void MX_TIM2_Init(void);
static void MX_RTC_Init(void);
/* USER CODE BEGIN PFP */

// State Machine States ####################################################### //
void ENTER_STATE_INITIALISATION() {
	// state newly entered; reset event timeout timer
	LastEvent = get_RTC_UNIX_TIME(&myRTC);

	// start loop counter
	loop_counter = 0;

	// load stored alarm times from EEPROM
	uint8_t hour_buffer = 0;
	uint8_t minute_buffer = 0;
	uint8_t timer_index_buffer = 0;

	// load WDA alarm times from EEPROM
	AT34C04_Read_VReg_unit8(&myAT34C04, EEPROM_WDA_HOUR_ADDR, &hour_buffer);
	AT34C04_Read_VReg_unit8(&myAT34C04, EEPROM_WDA_MINUTE_ADDR, &minute_buffer);
	// store in RTC
	set_WDA_Hour(&myRTC, hour_buffer);
	set_WDA_Minute(&myRTC, minute_buffer);

	// load OTA alarm times from EEPROM
	AT34C04_Read_VReg_unit8(&myAT34C04, EEPROM_OTA_HOUR_ADDR, &hour_buffer);
	AT34C04_Read_VReg_unit8(&myAT34C04, EEPROM_OTA_MINUTE_ADDR, &minute_buffer);
	// store in RTC
	set_OTA_Hour(&myRTC, hour_buffer);
	set_OTA_Minute(&myRTC, minute_buffer);

	// load TIMER1 values from EEPROM
	AT34C04_Read_VReg_unit8(&myAT34C04, EEPROM_TIMER1_ADDR, &timer_index_buffer);
	// store locally
	TEMP_TIMER1_INDEX = timer_index_buffer;

	// load TIMER2 values from EEPROM
	AT34C04_Read_VReg_unit8(&myAT34C04, EEPROM_TIMER2_ADDR, &timer_index_buffer);
	// store locally
	TEMP_TIMER2_INDEX = timer_index_buffer;

	// load Quicksetting 1 values from EEPROM
	AT34C04_Read_VReg_unit8(&myAT34C04, EEPROM_QS1_ADDR, &timer_index_buffer);
	// store locally
	TEMP_QS1_INDEX = timer_index_buffer;

	// load Quicksettin 2 values from EEPROM
	AT34C04_Read_VReg_unit8(&myAT34C04, EEPROM_QS2_ADDR, &timer_index_buffer);
	// store locally
	TEMP_QS2_INDEX = timer_index_buffer;

	// next state:
	nextState = STATE_STANDBY;
}

void ENTER_STATE_STANDBY(){
	// A: One time operations when a state is newly entered -----------
	if (nextState != currentState) {
		// state newly entered; reset event timeout timer
		LastEvent = get_RTC_UNIX_TIME(&myRTC);

		// disable LCD background illumination
		brightness_LCD_backlight = 0;

		// disable Keypad Background illumination
		brightness_keypad = 0;

		// deactivate indicator LEDs
		HMI_reset_all_LED_b(&myHMI);
		HMI_Write(&myHMI);
		// One time setup finished
		currentState = nextState;
	}

	// B: Normal operations of the state ------------------------------


	// display current time
	LCD_Write_Number(&myLCD, LCD_LEFT, get_RTC_Hour(&myRTC), 1);
	LCD_Write_Number(&myLCD, LCD_RIGHT, get_RTC_Minute(&myRTC), 2);

	// blink colon roughly every 500 ms /TODO add seconds blink
	LCD_Write_Colon(&myLCD, blink_signal_slow);

	// Send LCD Buffer
	LCD_SendBuffer(&myLCD);

	// show TIMER1 status
	// display Timer states
	HMI_reset_all_LED_b(&myHMI);
	HMI_Write_LED_b(&myHMI, HMI_LED_TIMER1,
			(get_TIMER1_State_Running(&myRTC) == ALARM_STATE_RUNNING) ? 1 : 0);
	HMI_Write_LED_b(&myHMI, HMI_LED_TIMER2,
			(get_TIMER2_State_Running(&myRTC) == ALARM_STATE_RUNNING) ? 1 : 0);
	HMI_Write(&myHMI);

	// C: conditions for changing the state ---------------------------

	// check for interrupts at HMI, but let the next state deal with it
	if (HMI_Read_Interrupt(&myHMI, HMI_BTN_ANY) == INTERRUPT) {
		// when any button is pressed, go to illuminated state
		nextState = STATE_STANDBY_LIGHT;
	}

	// check if encoder was turned
	encoder_pos = HMI_Encoder_position(&myHMI);

	if (encoder_pos != 0) {
		// encoder was moved
		nextState = STATE_STANDBY_LIGHT;
	}

	// D: timeout conditions ------------------------------------------

	// no timeout, this is the default state
}

void ENTER_STATE_STANDBY_LIGHT() {
	// A: One time operations when a state is newly entered -----------
	if (nextState != currentState) {
		// state newly entered; reset event timeout timer
		LastEvent = get_RTC_UNIX_TIME(&myRTC);

		// reset loop counter
		loop_counter = 0;

		// One time setup finished
		currentState = nextState;
	} else {
		// only called when this is not a state change

	}

	// B: Normal operations of the state ------------------------------

	// display current time
	LCD_Write_Number(&myLCD, LCD_LEFT, get_RTC_Hour(&myRTC), 1);
	LCD_Write_Number(&myLCD, LCD_RIGHT, get_RTC_Minute(&myRTC), 2);

	// blink colon roughly every 500 ms /TODO add seconds blink
	LCD_Write_Colon(&myLCD, blink_signal_slow);

	// Send LCD Buffer
	LCD_SendBuffer(&myLCD);

	// set Alarm LEDs
	HMI_reset_all_LED_b(&myHMI);
	HMI_Write_LED_b(&myHMI, HMI_LED_WDA, get_ALARM_WDA_Mode(&myRTC));
	HMI_Write_LED_b(&myHMI, HMI_LED_OTA, get_ALARM_OTA_Mode(&myRTC));
	// display Timer states
	HMI_Write_LED_b(&myHMI, HMI_LED_TIMER1,
			(get_TIMER1_State_Running(&myRTC) == ALARM_STATE_RUNNING) ? 1 : 0);
	HMI_Write_LED_b(&myHMI, HMI_LED_TIMER2,
			(get_TIMER2_State_Running(&myRTC) == ALARM_STATE_RUNNING) ? 1 : 0);

	HMI_Write(&myHMI);

	// enable LCD Background illumination
	brightness_LCD_backlight = brightness_backlight_default;

	// enable Keypad Background illumination
	brightness_keypad = brightness_keypad_default;

	// if any button was pressed, reset the timeout timer
	if (HMI_Read_Interrupt(&myHMI, HMI_BTN_ANY) != 0x0000) {
		// reset event timeout timer
		LastEvent = get_RTC_UNIX_TIME(&myRTC);
	}

	// adjust brightness of Lamp
	if (LAMP_state == 1) {
		// lamp is on, adjust the brightness

		// check if encoder was turned
		int encoder_pos_temp = HMI_Encoder_position(&myHMI);
		if (encoder_pos_temp != 0) {
			// encoder was moved; adjust the brightness
			encoder_pos += encoder_pos_temp;

			// set brightness; /2 because of double steps of encoder
			LAMP_brightness_setting += (encoder_pos/2) * PWM_CH_LAMP_MANUAL_STEP;

			// ensure limits
			if (LAMP_brightness_setting < PWM_CH_LAMP_MIN) {
				LAMP_brightness_setting = PWM_CH_LAMP_MIN;
			}
			if (LAMP_brightness_setting > PWM_CH_LAMP_MAX) {
				LAMP_brightness_setting = PWM_CH_LAMP_MAX;
			}

			// reset encoder
			encoder_pos = 0;

			// reset event timeout timer
			LastEvent = get_RTC_UNIX_TIME(&myRTC);
		}

	} else {
		// lamp is off but movement of the encoder resets the timeout
		if (HMI_Encoder_position(&myHMI) != 0) {
			// reset event timeout timer
			LastEvent = get_RTC_UNIX_TIME(&myRTC);
		}
	}

	// C: conditions for changing the state ---------------------------

	// check if WDA button is currently pressed
	if (HMI_Read_BTN(&myHMI, HMI_BTN_WDA) == BUTTON_PRESSED) {

		// switch to STATE_WDA_SHOW
		nextState = STATE_WDA_SHOW;
	}

	// check if OTA button is currently pressed
	if (HMI_Read_BTN(&myHMI, HMI_BTN_OTA) == BUTTON_PRESSED) {

		// switch to STATE_OTA_SHOW
		nextState = STATE_OTA_SHOW;
	}

	// check if Timer Date button is currently pressed
	if ((HMI_Read_BTN(&myHMI, HMI_BTN_TIME_DATE) == BUTTON_PRESSED) && (HMI_BTN_TIME_DATE_LOCK == 0) ) {

		// switch to STATE_TIME_DATE_SHOW
		nextState = STATE_TIME_DATE_SHOW;
	}

	// check if Timer1 button is currently pressed
	if (HMI_Read_BTN(&myHMI, HMI_BTN_TIMER1) == BUTTON_PRESSED) {

		// switch to STATE_TIMER1
		nextState = STATE_TIMER1;
	}

	// check if Timer2 button is currently pressed
	if (HMI_Read_BTN(&myHMI, HMI_BTN_TIMER2) == BUTTON_PRESSED) {

		// switch to STATE_TIMER2
		nextState = STATE_TIMER2;
	}

	// check if encoder button is currently pressed
	if (HMI_Read_BTN(&myHMI, HMI_BTN_ENCODER) == BUTTON_PRESSED) {
		//prevent timeout
		LastEvent = get_RTC_UNIX_TIME(&myRTC);

		// increment encoder button counter if unlocked
		if (HMI_BTN_ENCODER_LOCK == 0) {
			HMI_BTN_ENCODER_LONG_COUNTER += 1;
		}
	}
	// if the threshold for a longpress is reached, set the new state and lock the encoder button
	if (HMI_BTN_ENCODER_LONG_COUNTER >= HMI_LONG_PRESS_THRESHOLD) {
		// reset the counter to prevent loop
		HMI_BTN_ENCODER_LONG_COUNTER = 0;

		// when one of the alarms is in pre-alarm, end the alarm
		// otherwise toggle the main lamp
		if(get_WDA_State(&myRTC) == ALARM_STATE_PRE_ALARM) {
			// skip this alarm but keep it active in general
			set_WDA_ALARM_SKIP(&myRTC);
		} else if(get_OTA_State(&myRTC) == ALARM_STATE_PRE_ALARM) {
			// skip this alarm but keep it active in general
			set_OTA_ALARM_SKIP(&myRTC);
		} else {
			// toggle LAMP in next state
			nextState = STATE_TOGGLE_LAMP;
		}
		// lock the encoder button
		HMI_BTN_ENCODER_LOCK = 1;
	}


	// D: timeout conditions ------------------------------------------

	// check timeout
	if (get_RTC_UNIX_TIME(&myRTC) > LastEvent + TIMEOUT_LONG) {
		// timeout reached

		//return to other state
		nextState = STATE_STANDBY;
	}
}

void ENTER_STATE_TOGGLE_LAMP() {
	// A: One time operations when a state is newly entered -----------
	if (nextState != currentState) {
		// state newly entered; reset event timeout timer
		LastEvent = get_RTC_UNIX_TIME(&myRTC);

		// start loop counter
		loop_counter = 0;

		// One time setup finished
		currentState = nextState;
	}

	// B: Normal operations of the state ------------------------------

	// Toggle Lamp
	(LAMP_state) ? (LAMP_state = 0) : (LAMP_state = 1);

	// C: conditions for changing the state ---------------------------

	// none

	// D: timeout conditions ------------------------------------------

	// Immediate timeout, return to standby

	nextState = STATE_STANDBY_LIGHT;
}
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
int main(void)
{
  /* MCU Configuration--------------------------------------------------------*/

  /* Reset of all peripherals, Initializes the Flash interface and the Systick. */
  HAL_Init();

  /* Configure the system clock */
  SystemClock_Config();

  /* Initialize all configured peripherals */
  MX_GPIO_Init();
  MX_ADC1_Init();
  MX_I2C2_Init();
  MX_TIM1_Init();
  MX_TIM3_Init();
  MX_USART2_UART_Init();
  MX_TIM2_Init();
  MX_RTC_Init();
  /* USER CODE BEGIN 2 */

	// Setup periphery ##############################################
	// Initialize HMI (Port Expander, Encoder and DFPlayer
	HMI_Setup(&myHMI, 		// SX1503 object
			&hi2c2,				// I2C Handle
			nI_O_INT_GPIO_Port,	// Interrupt pin port
			nI_O_INT_Pin,		// Interrupt pin
			&htim1,
			&huart2,
			DFP_Audio_en_GPIO_Port,
			DFP_Audio_en_Pin);

	// SET Inputs and Outputs to the default configuration (reset)
	HMI_defaultConfig(&myHMI);

	// Setup LED Lights #############################################
	// set brightness to 0 before starting the PWM timers
	HMI_set_PWM(&myHMI, PWM_CH_Keypad, 0);
	HMI_set_PWM(&myHMI, PWM_CH_LCD, 0);
	HMI_set_PWM(&myHMI, PWM_CH_LAMP, 0);

	// start PWM Timers
	HAL_TIM_PWM_Start(&htim2, TIM_CHANNEL_2); // PWM_CH_Keypad
	HAL_TIM_PWM_Start(&htim3, TIM_CHANNEL_1); // PWM_CH_LCD
	HAL_TIM_PWM_Start(&htim3, TIM_CHANNEL_2); // PWM_CH_LAMP

	// Setup Encoder ################################################
	HAL_TIM_Encoder_Start(&htim1, TIM_CHANNEL_ALL);

	// Setup RTC ####################################################
	// Initialize RTC RV3028
	RTC_Setup(&myRTC,	 		// RV3028 handle
			&hi2c2,				// I2C Handle
			RTC_INT_GPIO_Port,	// Interrupt pin port
			RTC_INT_Pin			// Interrupt pin
	);

	// Setup LCD ####################################################
	// Setup LCD object
	LCD_Setup(&myLCD, 	// SX1503 object
			&hi2c2		// I2C Handle
	);

	// Initialize LCD
	LCD_INIT(&myLCD);

	// Enable LCD
	LCD_Enable(&myLCD);

	// blink all segments
	LCD_Segment_AllOn(&myLCD);
	HAL_Delay(1000);
	LCD_Segment_normal(&myLCD);

	// Setup EEPROM #################################################
	// Initialize EEPROM
	AT34C04_Initialize(
			&myAT34C04, // EEPROM object
			0x0,		// Address pin A0 value
			0x0,		// Address pin A1 value
			0x0,		// Address pin A2 value
			&hi2c2		// I2C Handle
	);

	// Setup MP3 ####################################################
	// disable MP3 Player
	DFP_Disable(&myHMI); // TODO does not work

	// Setup ADC ####################################################
	// load preprogrammed calibration values
	HAL_ADCEx_Calibration_Start(&hadc1);

	// DEBUG code
	// test alarm

/*
	// set time and date of RTC
	set_RTC_Day(&myRTC, 10);
	set_RTC_Month(&myRTC, 12);
	set_RTC_Year(&myRTC, 22);
	set_RTC_Hour(&myRTC, 9);
	set_RTC_Minute(&myRTC, 0);
	set_RTC_Second(&myRTC, 45);

	// WDA time for test purpose

	TEMP_TIME_HOUR = 9;
	TEMP_TIME_MINUTE = 2;

	set_WDA_Hour(&myRTC, TEMP_TIME_HOUR);
	set_WDA_Minute(&myRTC, TEMP_TIME_MINUTE);
	// save WDA time to EEPROM
	uint8_t temp_buffer_hour = TEMP_TIME_HOUR;
	uint8_t temp_buffer_minute = TEMP_TIME_MINUTE;
	// save hour to EEPROM
	AT34C04_Write_VReg_unit8(&myAT34C04, EEPROM_WDA_HOUR_ADDR, &temp_buffer_hour);
	// save minute to EEPROM
	AT34C04_Write_VReg_unit8(&myAT34C04, EEPROM_WDA_MINUTE_ADDR, &temp_buffer_minute);

	// enable WDA alarm
	set_ALARM_WDA_Mode(&myRTC, ALARM_MODE_ACTIVE);*/


  /* USER CODE END 2 */

  /* Infinite loop */
  /* USER CODE BEGIN WHILE */

	while (1) {
		// create blink pattern #####################################

		// cyclic counter
		loop_counter += 1;
		if (loop_counter >= 255) {
			loop_counter = 0;
		}
		// set blink pattern based on counter
		if((loop_counter % blink_fast_interval) == 0) {
			blink_signal_fast = !blink_signal_fast;
		}

		if((loop_counter % blink_slow_interval) == 0) {
			blink_signal_slow = !blink_signal_slow;
		}

		// read battery level #######################################
		HAL_ADC_Start(&hadc1);
		HAL_ADC_PollForConversion(&hadc1, HAL_MAX_DELAY);
		uint32_t raw_battery_value = HAL_ADC_GetValue(&hadc1);
		// in volt
		float battery_voltage = raw_battery_value * VBAT_const;

		// TODO add low battery action, e.g. display "BAT"

		// Set LEDs #################################################
		// Set Backlight LEDs
		HMI_set_PWM(&myHMI, PWM_CH_LCD, brightness_LCD_backlight);
		// Set Keypad LEDs
		HMI_set_PWM(&myHMI, PWM_CH_Keypad, brightness_keypad);

		// Set Lamp Level
		// from high priority to low priority
		if(
				(get_TIMER1_State_Running(&myRTC) == ALARM_STATE_ALARM) ||
				(get_TIMER2_State_Running(&myRTC) == ALARM_STATE_ALARM)) {
			// don't overwrite Lamp setting
		} else if (
				(get_WDA_State(&myRTC) == ALARM_STATE_ALARM) ||
				(get_WDA_State(&myRTC) == ALARM_STATE_PRE_ALARM) ||
				(get_OTA_State(&myRTC) == ALARM_STATE_ALARM) ||
				(get_OTA_State(&myRTC) == ALARM_STATE_PRE_ALARM)) {
			// don't overwrite Lamp setting
		} else {
			// no alarms, set default
			LAMP_brightness_current_level = LAMP_brightness_setting * LAMP_state;
		}

		HMI_set_PWM(&myHMI, PWM_CH_LAMP, LAMP_brightness_current_level);

		// Read RTC #################################################
		RTC_Get_Time(&myRTC);

		// Read Button evens ########################################
		/*
		 * Get button states, but not when it is waking up from unlit standby states
		 * - this preserves the button presses while waking up improving the UX
		 */
		if((currentState == STATE_STANDBY) && (nextState == STATE_STANDBY_LIGHT)) {
			// don't get new button presses
		} else if ((currentState == STATE_TIMER1_SHOW_STANDBY) && (nextState == STATE_TIMER1_SHOW)) {
			// don't get new button presses
		} else if ((currentState == STATE_TIMER2_SHOW_STANDBY) && (nextState == STATE_TIMER2_SHOW)) {
			// don't get new button presses
		} else {
			// get current button states
			HMI_Read_GPIOs(&myHMI);
		}

		// reset button locks after long press or state changes
		if (HMI_Read_BTN(&myHMI, HMI_BTN_ENCODER) == BUTTON_NOT_PRESSED) {
			HMI_BTN_ENCODER_LOCK = 0;
			HMI_BTN_ENCODER_LONG_COUNTER = 0;
		}
		if (HMI_Read_BTN(&myHMI, HMI_BTN_WDA) == BUTTON_NOT_PRESSED) {
			HMI_BTN_WDA_LOCK = 0;
			HMI_BTN_WDA_LONG_COUNTER = 0;
		}
		if (HMI_Read_BTN(&myHMI, HMI_BTN_OTA) == BUTTON_NOT_PRESSED) {
			HMI_BTN_OTA_LOCK = 0;
			HMI_BTN_OTA_LONG_COUNTER = 0;
		}
		if (HMI_Read_BTN(&myHMI, HMI_BTN_TIME_DATE) == BUTTON_NOT_PRESSED) {
			HMI_BTN_TIME_DATE_LOCK = 0;
			HMI_BTN_TIME_DATE_LONG_COUNTER = 0;
		}
		if (HMI_Read_BTN(&myHMI, HMI_BTN_TIMER1) == BUTTON_NOT_PRESSED) {
			HMI_BTN_TIMER1_LOCK = 0;
			HMI_BTN_TIMER1_LONG_COUNTER = 0;
		}
		if (HMI_Read_BTN(&myHMI, HMI_BTN_TIMER2) == BUTTON_NOT_PRESSED) {
			HMI_BTN_TIMER2_LOCK = 0;
			HMI_BTN_TIMER2_LONG_COUNTER = 0;
		}

		// Check on timer and alarms ################################
		// Check Timer 1
		if(get_TIMER1_State_Running(&myRTC) == ALARM_STATE_ALARM) {
			// Enter Timer 1 state
			nextState = STATE_TIMER1_ALARM;
		}
		if(get_TIMER2_State_Running(&myRTC) == ALARM_STATE_ALARM) {
			// Enter Timer 2 state
			nextState = STATE_TIMER2_ALARM;
		}

		// Check alarm state
		if(get_WDA_State(&myRTC) == ALARM_STATE_PRE_ALARM) {
			// Dimm LED Lamp
			LAMP_brightness_current_level = (uint16_t) (get_WDA_preAlarm_time(&myRTC) * (float)PWM_CH_LAMP_MAX);
			// forces state during pre alarm
			nextState = STATE_STANDBY_LIGHT;
		}
		if(get_WDA_State(&myRTC) == ALARM_STATE_ALARM) {
			// forced state during alarm
			nextState = STATE_WDA_ALARM;
		}
		if(get_OTA_State(&myRTC) == ALARM_STATE_PRE_ALARM) {
			// Dimm LED Lamp
			LAMP_brightness_current_level = (uint16_t) (get_OTA_preAlarm_time(&myRTC) * (float)PWM_CH_LAMP_MAX);
			// forces state during pre alarm
			nextState = STATE_STANDBY_LIGHT;
		}
		if(get_OTA_State(&myRTC) == ALARM_STATE_ALARM) {
			// forced state during alarm
			nextState = STATE_OTA_ALARM;
		}

		// State Machine ############################################
		switch (nextState) {

		case STATE_INITIALISATION:
			ENTER_STATE_INITIALISATION();
			break;

		case STATE_STANDBY:
			ENTER_STATE_STANDBY();
			break;

		case STATE_STANDBY_LIGHT:
			ENTER_STATE_STANDBY_LIGHT();
			break;

		case STATE_TOGGLE_LAMP:
			ENTER_STATE_TOGGLE_LAMP();
			break;

		case STATE_WDA_SHOW:
			ENTER_STATE_WDA_SHOW();
			break;

		case STATE_WDA_ALARM:
			ENTER_STATE_WDA_ALARM();
			break;

		case STATE_WDA_TOGGLE:
			ENTER_STATE_WDA_TOGGLE();
			break;

		case STATE_WDA_SET:
			ENTER_STATE_WDA_SET();
			break;

		case STATE_WDA_SET_HOUR:
			ENTER_STATE_WDA_SET_HOUR();
			break;

		case STATE_WDA_SET_MINUTE:
			ENTER_STATE_WDA_SET_MINUTE();
			break;

		case STATE_WDA_SET_SAVE:
			ENTER_STATE_WDA_SET_SAVE();
			break;

		case STATE_OTA_SHOW:
			ENTER_STATE_OTA_SHOW();
			break;

		case STATE_OTA_ALARM:
			ENTER_STATE_OTA_ALARM();
			break;
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

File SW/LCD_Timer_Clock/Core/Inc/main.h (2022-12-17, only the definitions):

#define nI_O_INT_Pin GPIO_PIN_7
#define nI_O_INT_GPIO_Port GPIOB
#define VBAT_d2_Pin GPIO_PIN_0
#define VBAT_d2_GPIO_Port GPIOA
#define LED_Keypad_PWM_Pin GPIO_PIN_1
#define LED_Keypad_PWM_GPIO_Port GPIOA
#define UART_MCU_2_DFP_Pin GPIO_PIN_2
#define UART_MCU_2_DFP_GPIO_Port GPIOA
#define UART_DFP_2_MCU_Pin GPIO_PIN_3
#define UART_DFP_2_MCU_GPIO_Port GPIOA
#define DFP_Audio_en_Pin GPIO_PIN_4
#define DFP_Audio_en_GPIO_Port GPIOA
#define RTC_INT_Pin GPIO_PIN_5
#define RTC_INT_GPIO_Port GPIOA
#define LCD_BG_PWM_Pin GPIO_PIN_6
#define LCD_BG_PWM_GPIO_Port GPIOA
#define LED_Light_PWM_Pin GPIO_PIN_7
#define LED_Light_PWM_GPIO_Port GPIOA
#define ENC_A_Pin GPIO_PIN_8
#define ENC_A_GPIO_Port GPIOA
#define I2C_SCL_Pin GPIO_PIN_11
#define I2C_SCL_GPIO_Port GPIOA
#define I2C_SDA_Pin GPIO_PIN_12
#define I2C_SDA_GPIO_Port GPIOA
#define ENC_B_Pin GPIO_PIN_3
#define ENC_B_GPIO_Port GPIOB
#define STATE_INITIALISATION 0
#define STATE_STANDBY 1
#define STATE_STANDBY_LIGHT 2
#define STATE_TOGGLE_LAMP 3
#define STATE_WDA_SHOW 4
#define STATE_WDA_ALARM 401
#define STATE_WDA_TOGGLE 5
#define STATE_WDA_SET 6
#define STATE_WDA_SET_HOUR 601
#define STATE_WDA_SET_MINUTE 602
#define STATE_WDA_SET_SAVE 603
#define STATE_OTA_SHOW 7
#define STATE_OTA_ALARM 701
#define STATE_OTA_TOGGLE 8
#define STATE_OTA_SET 9
#define STATE_OTA_SET_HOUR 901
#define STATE_OTA_SET_MINUTE 902
#define STATE_OTA_SET_SAVE 903
#define STATE_TIME_DATE_SHOW 10
#define STATE_TIME_DATE_SET 11
#define STATE_TIME_DATE_SET_YEAR 1101
#define STATE_TIME_DATE_SET_DAY 1102
#define STATE_TIME_DATE_SET_MONTH 1103
#define STATE_TIME_DATE_SET_HOUR 1104
#define STATE_TIME_DATE_SET_MINUTE 1105
#define STATE_TIME_DATE_SET_SAVE 1106
#define STATE_TIMER1 12
#define STATE_TIMER1_SHOW 1201
#define STATE_TIMER1_SHOW_STANDBY 1202
#define STATE_TIMER1_SET 1203
#define STATE_TIMER1_SET_RUN 1204
#define STATE_TIMER1_ALARM 1205
#define STATE_TIMER2 13
#define STATE_TIMER2_SHOW 1301
#define STATE_TIMER2_SHOW_STANDBY 1302
#define STATE_TIMER2_SET 1303
#define STATE_TIMER2_SET_RUN 1304
#define STATE_TIMER2_ALARM 1305
#define STATE_QUICKSETTING1_SET 14
#define STATE_QUICKSETTING1_SET_SAVE 1401
#define STATE_QUICKSETTING2_SET 15
#define STATE_QUICKSETTING2_SET_SAVE 1501
#define STATE_TEMPLATE 99
#define EEPROM_WDA_HOUR_ADDR 1
#define EEPROM_WDA_MINUTE_ADDR 2
#define EEPROM_OTA_HOUR_ADDR 3
#define EEPROM_OTA_MINUTE_ADDR 4
#define EEPROM_TIMER1_ADDR 5
#define EEPROM_TIMER2_ADDR 6
#define EEPROM_QS1_ADDR 7
#define EEPROM_QS2_ADDR 8

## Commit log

2022-03-26 add new pcb project
    [Sheet1_Overview.SchDoc, Sheet2_Power_Supply.SchDoc, Timer_Clock.PrjPcb]
2022-03-27 starting schematic
    [Sheet1_Overview.SchDoc, Sheet2_Power_Supply.SchDoc, Sheet3_MCU.SchDoc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]
2022-03-28 add rtc
    [Sheet3_MCU.SchDoc]
2022-04-15 work in progress
    [Sheet1_Overview.SchDoc, Sheet3_MCU.SchDoc, Sheet4_LCD.SchDoc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]
2022-04-16 progress on first draft
    [Sheet2_Power_Supply.SchDoc, Sheet3_MCU.SchDoc, Sheet4_LCD.SchDoc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]
2022-04-18 place first PCB
    [Sheet1_Overview.SchDoc, Sheet5_LCD.SchDoc]
2022-04-18 add screw
    [Sheet1_Overview.SchDoc]
2022-04-18 fix 3d model
    [Sheet1_Overview.SchDoc, Timer_Clock.PrjPcb]
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2022-04-18 Starting placement
    [Sheet1_Overview.SchDoc, Sheet2_Power_Supply.SchDoc, Sheet3_MCU.SchDoc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]
2022-04-19 rename folder; add 3d export
    [PCB_BOT.step, Sheet1_Overview.SchDoc, Sheet2_Power_Supply.SchDoc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]
2022-04-19 move folder again
    [PCB_BOT.step, Sheet1_Overview.SchDoc, Sheet2_Power_Supply.SchDoc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]
2022-04-20 move files around
    [Sheet4_LCD.SchDoc, Sheet5_LCD.SchDoc, Timer_Clock.PrjPcb]
2022-04-20 first full compile
    [Sheet1_Overview.SchDoc, Sheet2_Power_Supply.SchDoc, Sheet3_MCU.SchDoc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]
2022-05-07 prepare part ordering
    [BOM_PartType-Timer_Clock.xlsx, Sheet2_Power_Supply.SchDoc, Sheet3_MCU.SchDoc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]
2022-05-08 import latest schematic changes; prepare to change layerstack
    [Sheet5_LCD.SchDoc, Timer_Clock.PrjPcb]
2022-05-08 progress routing
    [Sheet5_LCD.SchDoc]
2022-05-09 finished routing
    [Sheet5_LCD.SchDoc]
2022-05-13 Rough placement
    [Sheet2_Power_Supply.SchDoc, Sheet3_MCU.SchDoc]
2022-05-14 started routing
    [Sheet2_Power_Supply.SchDoc, Sheet4_LCD_Interface.SchDoc, Sheet5_LCD.SchDoc]
2022-05-15 First Layout Draft
    [Sheet1_Overview.SchDoc, Sheet2_Power_Supply.SchDoc, Sheet3_MCU.SchDoc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]
2022-05-15 starting to prepare for delivery
    [Sheet4_LCD_Interface.SchDoc, Sheet5_LCD.SchDoc, Timer_Clock.PrjPcb]
2022-05-15 prepared order
    [BOM_PartType-Timer_Clock.xlsx, BOM_PartType-Timer_Clock_BOT(AlarmClock_JLC).xlsx, BOM_PartType-Timer_Clock_TOP(AlarmClock_JLC).xlsx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]
2022-05-15 performed order
    [BOM_PartType-Timer_Clock_TOP(AlarmClock_JLC).xlsx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]
2022-05-24 update model
    [Ring_Top_Silicone_Mold.stl]
2022-05-24 Fix error
    [Ring_Top_Silicone_Mold.stl]
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2022-06-04 update 3d models
    [Encoder_Gear v3.stl, PCB_Bot_Mount v7.stl, PCB_Top_Mount v8.stl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]
2022-06-06 new findings and display and MP3 mostly working (mp3 layout error but tested on bench)
    [main.c]
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2022-06-16 #1: clean up variant names (consolidated into Alarm Clock)
    [Timer_Clock_BOT.PrjPcb, Timer_Clock_TOP.PrjPcb]
2022-06-16 #1 corrected assembly: R505 = 0R, R502 = open
    [Timer_Clock_TOP.PrjPcb]
2022-06-16 #2: insert resistors for the LEDs of the buttons
    [LCD.SchDoc]
2022-06-16 #4 fixed output file names
    [BOM_PartType-Timer_Clock_BOT(Alarm Clock).xlsx, BOM_PartType-Timer_Clock_BOT(AlarmClock_JLC).xlsx, BOM_PartType-Timer_Clock_TOP(Alarm Clock).xlsx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]
2022-06-16 fixed #10 and #19
    Renamed signals to make sense
    [LCD.SchDoc, Sheet4_LCD_Interface.SchDoc]
2022-06-16 cleaned up power signals
    [LCD.SchDoc]
2022-06-16 fixed #11 changed to VBAT and added 0R to I2C
    [LCD.SchDoc, Timer_Clock_TOP.PrjPcb]
2022-06-16 fixed #31 - added pull downs to PWM signals
    [LCD.SchDoc]
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2022-06-16 fixed #8 - modify PA1, remove nUSB_PD_OK, add LCD_Keypad_PWM
    [LCD.SchDoc, Sheet1_Overview.SchDoc, Sheet3_MCU.SchDoc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]
2022-06-16 fixed #5 - remapped signal
    [LCD.SchDoc]
2022-06-16 add note about current
    [LCD.SchDoc]
2022-06-17 Fixed #3 - updated project parameter
    [Timer_Clock_TOP.PrjPcb]
2022-06-17 changed project parameter - #12
    [Timer_Clock_BOT.PrjPcb]
2022-06-17 #12 swap battery indicator charging/standby
    [Sheet2_Power_Supply.SchDoc, Timer_Clock_BOT.PrjPcb]
2022-06-17 #12 - IC400 pin1 was missing in assembly plan
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2022-06-17 #12 added missing pin 1 marking of DFPlayer
2022-06-17 #12 changed comment and ID of IC301
    [Sheet3_MCU.SchDoc]
2022-06-17 fixed #12 - added I2c addresses to all I2C devices
    [LCD.SchDoc, Sheet3_MCU.SchDoc, Sheet4_LCD_Interface.SchDoc]
2022-06-17 fixed #15 - switched source for ref supply
    [Sheet2_Power_Supply.SchDoc]
2022-06-17 fixed #16 - add pull-down
    [Sheet3_MCU.SchDoc]
2022-06-17 #7 implement new LEDs
    [LCD.SchDoc]
2022-06-17 moved signal away from GND
    [LCD.SchDoc]
2022-06-17 fixed #7 added heatsinks
    [LCD.SchDoc]
2022-06-17 #17 added pinheader for SWD
    [Sheet3_MCU.SchDoc]
2022-06-17 #17 added 0R after LDO
    [Sheet2_Power_Supply.SchDoc, Sheet3_MCU.SchDoc]
2022-06-17 #17 added high side switch
    [Sheet1_Overview.SchDoc, Sheet4_LCD_Interface.SchDoc]
2022-06-17 added USB detect signal to multiplexer
    [Sheet4_LCD_Interface.SchDoc]
2022-06-18 replaced High Power LEDs
    [LCD.SchDoc]
2022-06-18 placed heat sinks
    [LCD.SchDoc]
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2022-06-18 performed design checks, ready for manufacturing
    [Timer_Clock_TOP.PrjPcb]
2022-06-19 cleaned up schematic
    [Sheet1_Overview.SchDoc, Sheet2_Power_Supply.SchDoc, Sheet3_MCU.SchDoc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]
2022-06-19 addded and placed all new components
    [Sheet3_MCU.SchDoc, Sheet4_LCD_Interface.SchDoc]
2022-06-19 Finished placement and layout
    [Timer_Clock_BOT.PrjPcb]
2022-06-19 variant based export (no gerber)
    [BOM_PartType-Timer_Clock_BOT(Alarm Clock).xlsx, BOM_PartType-Timer_Clock_TOP(Alarm Clock).xlsx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]
2022-06-19 remove output file
    [LCD.SchDoc, Timer_Clock_BOT.PrjPcb, Timer_Clock_TOP.PrjPcb]
2022-06-19 generated complete export
    [BOM_PartType-Timer_Clock_BOT(Alarm Clock).xlsx, BOM_PartType-Timer_Clock_TOP(Alarm Clock).xlsx, LCD.SchDoc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]
2022-06-20 replaced LEDs with 2700K type
    [LCD.SchDoc, Timer_Clock_TOP.PrjPcb]
2022-06-20 fixed invisible polygon
    [Timer_Clock_BOT.PrjPcb]
2022-06-20 Ready for manufacturing (V2.0)
    [BOM_PartType-Timer_Clock_BOT(Alarm Clock).xlsx, BOM_PartType-Timer_Clock_TOP(Alarm Clock).xlsx, Timer_Clock_BOT.PrjPcb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]
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2022-07-03 fixed #33: increased R518, R519, R520
    [LCD.SchDoc, Timer_Clock_TOP.PrjPcb]
2022-07-03 regenerated exports after BOM change
    [BOM_PartType-Timer_Clock_TOP(Alarm Clock).xlsx, Timer_Clock_TOP.PrjPcb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]
2022-07-03 fixed #35: increased resistors
    [Sheet3_MCU.SchDoc, Timer_Clock_BOT.PrjPcb]
2022-07-03 fixed #34: increased resistors
    [Sheet3_MCU.SchDoc]
2022-07-03 regenerated outputs after BOM change
    [BOM_PartType-Timer_Clock_BOT(Alarm Clock).xlsx, BOM_PartType-Timer_Clock_TOP(Alarm Clock).xlsx, Timer_Clock_BOT.PrjPcb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]
2022-07-03 changed BOM export from excel to PDF
    [BOM_PartType-Timer_Clock_BOT(Alarm Clock).xlsx, BOM_PartType-Timer_Clock_TOP(Alarm Clock).xlsx, Timer_Clock_BOT.PrjPcb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]
2022-07-03 changed BOM export to html
    [PCB_BOT.GBL, PCB_BOT.GBO, PCB_BOT.GBS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]
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2022-08-13 fixed missing pwm output (TIM2 CH2 for Keypad LEDs).
    [SW.ioc, main.c, main.h]
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2022-08-14 add skeleton of state machine, fixed some formatting, start with RTC
    [HMI.c, main.c, main.h]
2022-08-17 fix which button causes reset of timeout
    [main.c]
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2022-08-20 fix state transition S1 to s4
    [main.c]
2022-11-13 performing test for encoder skip problem
    [SW.ioc, main.c]
2022-11-17 fix global variable problem
    [BL55072A.c, BL55072A.h, HMI.c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]
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2022-11-17 Revert "remove special flag for globals; fixed #43"
    [HMI.c, HMI.h, RV3028.c]
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2022-11-21 fix encoder stutter
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2022-11-22 safing to eeprom not working right now
    [main.c, main.h]
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2022-11-23 fixed bug with not storing index in EEPROM
    [main.c]
2022-11-23 reverted to uint8_t for EEPROM
    [main.c]
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2022-11-23 fixed missing button press reaction from waking from unlit standby
    [main.c]
2022-11-23 fixed LED not turning off in standby
    [main.c]
2022-11-24 replaced math include with custom round down function
    [main.c]
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2022-11-24 fix error where data could not be edited
    [main.c]
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2022-11-26 can now measure (rank was missing)
    [SW.ioc, main.c]
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2022-11-26 rename pin, didn't help
    [SW.ioc, main.h]
2022-12-07 perform button lock reset globally
    [main.c]
2022-12-09 fix confusion between mode and state, implement exiting pre alarm
    [RV3028.c, main.c]
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2022-12-09 fix looping issue with lamp on/off
    [main.c]
2022-12-10 ramp tested, minor bug fixed
    [HMI.h, RV3028.c, main.c]
2022-12-10 fixed remaining mode and state confusion
    [RV3028.c, main.c]
2022-12-10 fix mayor deadlock bug
    [RV3028.c, main.c]
2022-12-10 fix one time bug
    [main.c]
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2022-12-17 experiment with new case design
    [Encoder_Ring_V2 v9.stl, PCB_BOT_MOUNT_V2 v9.stl, PCB_Bot_Mount v7.stl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]
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2023-01-03 remove old files
    [Encoder_Gear v3.stl, Encoder_Ring_V2 v9.stl, PCB_BOT_MOUNT_V2 v9.stl]
2023-01-28 latest 3d models
    [Enclosure_Top.stl, Encoder_Gear.stl, Knob.stl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]

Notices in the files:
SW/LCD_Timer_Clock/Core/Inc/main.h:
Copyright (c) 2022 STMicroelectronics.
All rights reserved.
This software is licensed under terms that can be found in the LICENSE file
